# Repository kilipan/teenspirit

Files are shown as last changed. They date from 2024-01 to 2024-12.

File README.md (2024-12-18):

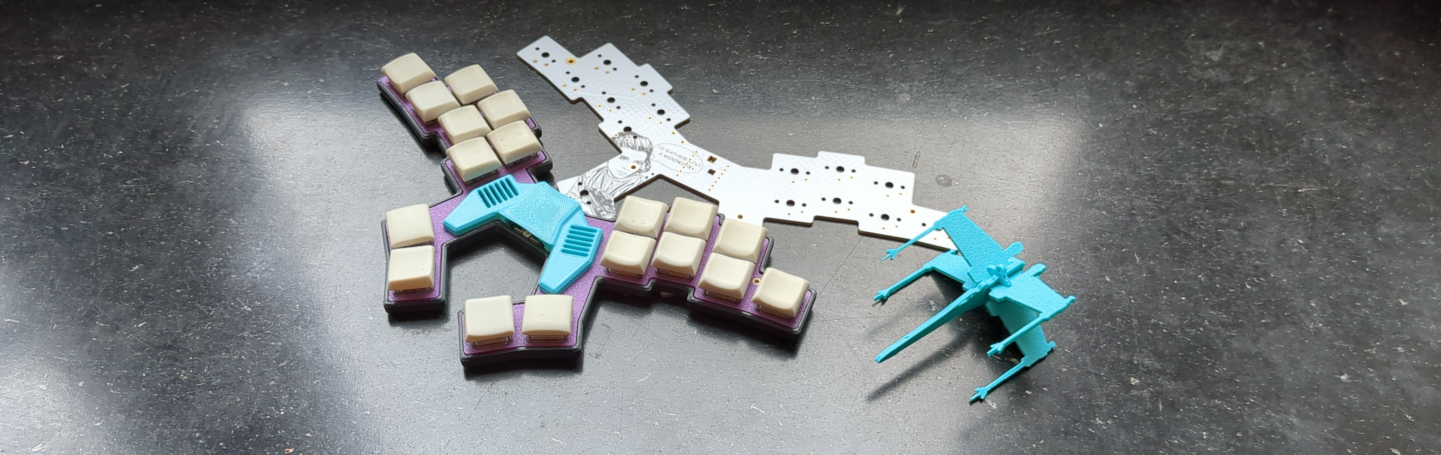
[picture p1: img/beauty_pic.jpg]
teenspirit


# Teenspirit
*I'd rather kiss a Wookiee!*

A not-so-space-invading 18-key ergonomic keyboard with two Piezo-buzzers and a retro-toy looking case.

## BOM
- 1 Teenspirit PCB
- 1 Seeed XIAO compatible controller, like e.g. [Miao](https://github.com/kilipan/miao)
- 9 sot23 diodes (common cathode), look for BAV70
- 18 kailh choc low profile switches
- 18 fitting keycaps

## Firmware
Currently [ZMK firmware](https://github.com/kilipan/zmk-config-teenspirit) and [FAK firmware](https://github.com/kilipan/fak-config/tree/main/keyboards/teenspirit) are available. Neither allows using the buzzers as of yet, but ZMK should soon™️! :)

## Production Files
All files are provided under CERN-OHL-S license.
### PCB
Gerbers for producing the PCB can be found in [`prod/pcb`](https://github.com/kilipan/teenspirit/tree/main/prod/pcb).

### Case
The fantastic case was designed by DizzySkizzo (`dizzyskizzo1337` on discord). Thank you for letting me use and open source this genius design!
Production files available in [`prod/case`](https://github.com/kilipan/teenspirit/tree/main/prod/case).
The case uses threaded heat-inserts of type `M2xL2xOD3` available for example [on Aliexpress](<https://de.aliexpress.com/item/1005006071488810.html>) (make sure to select the correct type! The linked listing has many different options).
Use 7mm screws (6 might also fit, if you want to cut it close).

## Example Keymap
Take this as an inspiration for how typing on this can work very well, not a fixed way to do things! :)

example keymap

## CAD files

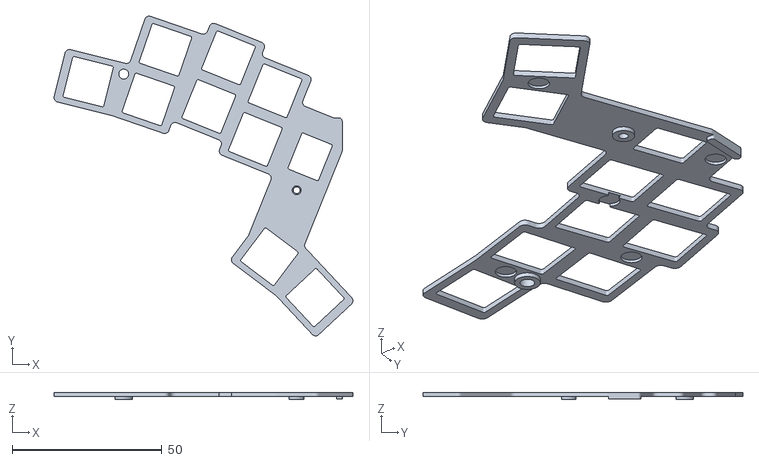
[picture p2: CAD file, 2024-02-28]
prod/case/Teenspiritcase/plateLEFT.stl
99.7 x 106.7 x 2.24

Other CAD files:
prod/case/Teenspiritcase/plateRIGHT.stl

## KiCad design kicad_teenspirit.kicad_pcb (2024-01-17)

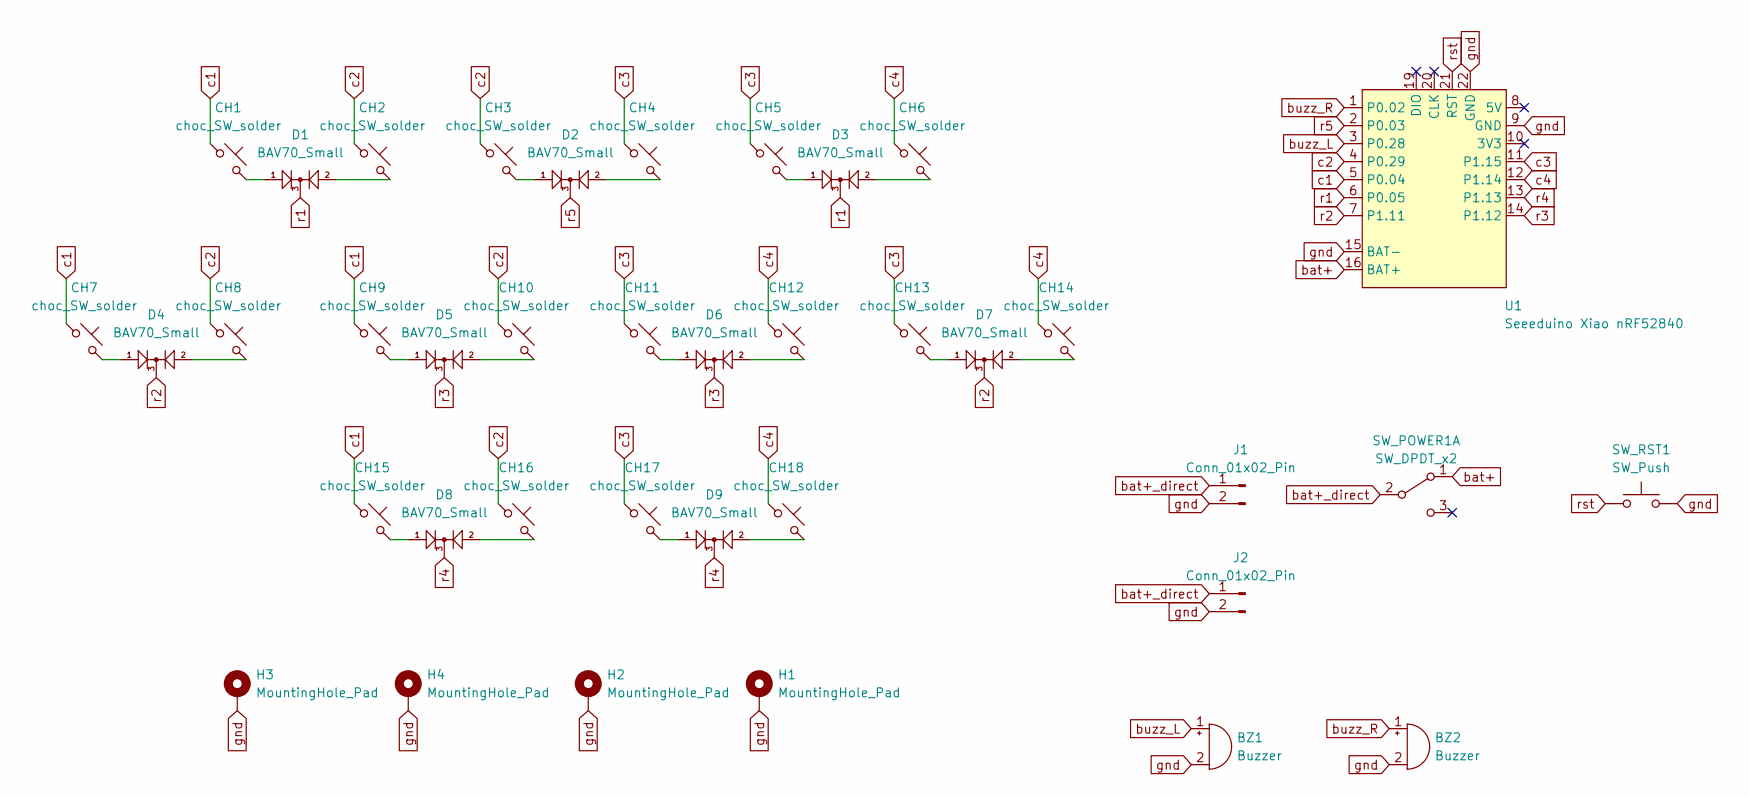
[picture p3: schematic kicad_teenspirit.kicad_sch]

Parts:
BZ1, BZ2: Buzzer; Buzzer_Mallory_AST1109MLTRQ
CH1, CH2, CH3, CH4, CH5, CH6, CH7, CH8, CH9, CH10, CH11, CH12, CH13, CH14, CH15, CH16, CH17, CH18: choc_SW_solder; SW_choc_v1_1u
D1, D2, D3, D4, D5, D6, D7, D8, D9: BAV70_Small; apfel_SOT-23_silkless
H1, H2, H3, H4: MountingHole_Pad; MountingHole_2.2mm_M2_Pad_Via_nosilk
J1: Conn_01x02_Pin; JST_GH_SM02B-GHS-TB_1x02-1MP_P1.25mm_Horizontal
J2: Conn_01x02_Pin; PinHeader_1x02_P2.54mm_Vertical
SW_POWER1: SW_DPDT_x2; SW_MSK12C02-HB
SW_RST1: SW_Push; SW_ResetSW
U1: Seeeduino Xiao nRF52840; Xiao_nRF52840_ACH_nosilk_cutout

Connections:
unnamed: CH1.2, D1.1 (A1)
unnamed: CH2.2, D1.2 (A2)
unnamed: CH3.2, D2.1 (A1)
unnamed: CH4.2, D2.2 (A2)
unnamed: CH5.2, D3.1 (A1)
unnamed: CH6.2, D3.2 (A2)
unnamed: CH7.2, D4.1 (A1)
unnamed: CH8.2, D4.2 (A2)
unnamed: CH9.2, D5.1 (A1)
unnamed: CH10.2, D5.2 (A2)
unnamed: CH11.2, D6.1 (A1)
unnamed: CH12.2, D6.2 (A2)
unnamed: CH13.2, D7.1 (A1)
unnamed: CH14.2, D7.2 (A2)
unnamed: CH15.2, D8.1 (A1)
unnamed: CH16.2, D8.2 (A2)
unnamed: CH17.2, D9.1 (A1)
unnamed: CH18.2, D9.2 (A2)
bat+: SW_POWER1.1 (A), U1.16 (BAT+)
bat+_direct: J1.1, J2.1, SW_POWER1.2 (B)
buzz_L: BZ1.1 (-), U1.3 (P0.28)
buzz_R: BZ2.1 (-), U1.1 (P0.02)
c1: CH1.1, CH7.1, CH9.1, CH15.1, U1.5 (P0.04)
c2: CH2.1, CH3.1, CH8.1, CH10.1, CH16.1, U1.4 (P0.29)
c3: CH4.1, CH5.1, CH11.1, CH13.1, CH17.1, U1.11 (P1.15)
c4: CH6.1, CH12.1, CH14.1, CH18.1, U1.12 (P1.14)
gnd: BZ1.2 (+), BZ2.2 (+), H1.1, H2.1, H3.1, H4.1, J1.2, J2.2, SW_RST1.2, U1.9 (GND), U1.15 (BAT-), U1.22 (GND)
r1: D1.3 (K), D3.3 (K), U1.6 (P0.05)
r2: D4.3 (K), D7.3 (K), U1.7 (P1.11)
r3: D5.3 (K), D6.3 (K), U1.14 (P1.12)
r4: D8.3 (K), D9.3 (K), U1.13 (P1.13)
r5: D2.3 (K), U1.2 (P0.03)
rst: SW_RST1.1, U1.21 (RST)

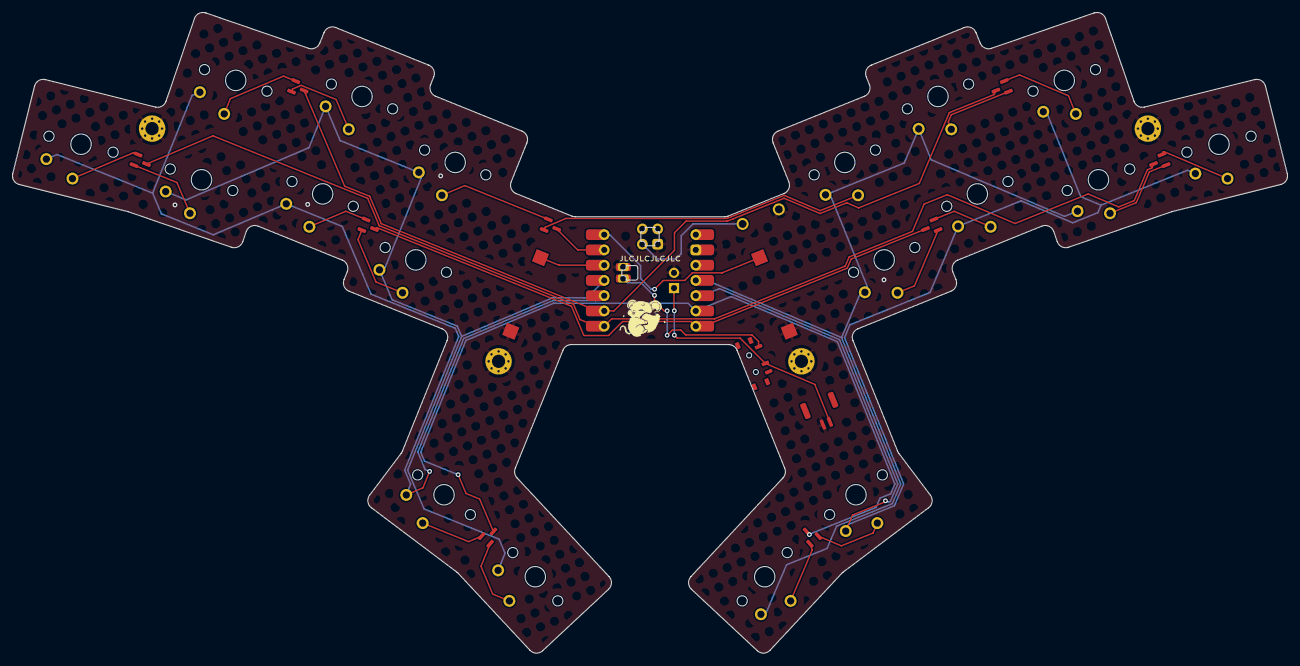
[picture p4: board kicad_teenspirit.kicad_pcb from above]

Board: 2 copper layers, 212.3 x 106.7 mm, 38 parts (1 on the bottom side), 33 nets.

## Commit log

2024-02-28 provide unrar'd case files
    [plateLEFT.stl, plateRIGHT.stl]
2024-06-17 add info on heat-inserts to README.md
2024-12-18 Add screw length to readme
